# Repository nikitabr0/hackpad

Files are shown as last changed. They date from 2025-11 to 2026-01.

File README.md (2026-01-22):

# nikitabr0's hackpad

[Demo video](https://youtu.be/7ATBC-yoFk0)

<table>
  <tr>
    <td>
    <td>
  </tr>
  <tr>
    <td>
    <td>
  </tr>
</table>   

My hackpad features 9 MX-style keyswitches and two EC11 rotary encoders. It has two modes: media control and gaming mode, the latter being mostly for simulators, that require large amounts of keybinds.

In media control mode the keys can be used for pausing, resuming and switching between audiotracks, as well as for using the calcuator (+, -, *, / and =), while the rotary encoders allow for audio volume and screen brightness control, with their switches set to muting audio and locking the screen.

In gaming mode all switches (including those of EC11s) register as F13-F22 presses, with the rotary encoders triggering Right CTRL + F13/14/15/16 on rotation. These keycodes were choosed as they are not included on most keyboards and thus largely unused.

The firmware if written in KMK for the sake of simplicity, although I may try rewriting it in QMK one day. The CAD was done in FreeCAD.

#

### Schematic


### PCB layout


### Case assembly



#

## Bill of materials:
- 1x Seeed XIAO RP2040 DIP
- 9x MX-style switches
- 2x EC11 rotary encoders
- 9x Blank DSA keycaps
- 11x Through-hole 1N4148 diodes
- 4x M3x5mx4mm heatset inserts

I will be printing the case by myself and as I already have some mounting hardware, I will be using it in this project:
- 4x M3x12 SHCS
- 3x M3x8 SHCS

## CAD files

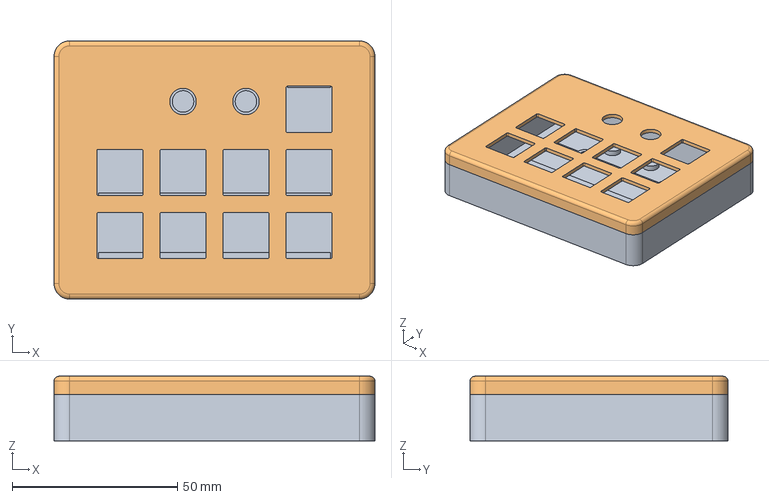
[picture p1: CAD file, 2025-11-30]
CAD/case.step
97.0 x 78.0 x 19.5 mm
Main
Lid

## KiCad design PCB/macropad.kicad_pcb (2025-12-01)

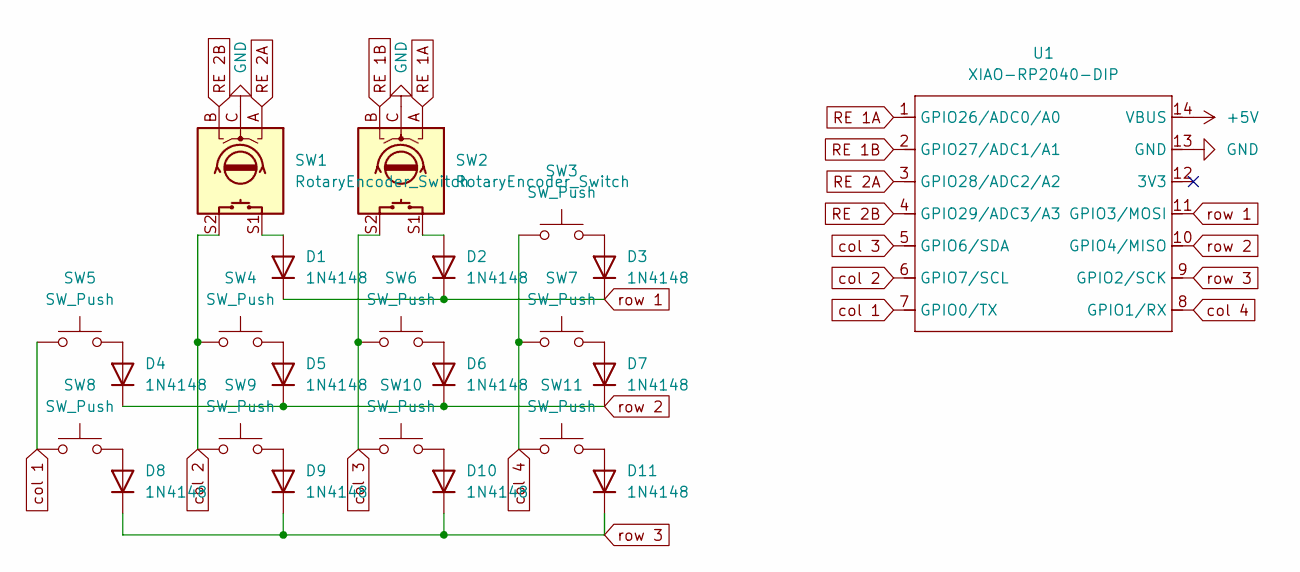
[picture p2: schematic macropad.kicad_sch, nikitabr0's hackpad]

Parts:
D1, D2, D3, D4, D5, D6, D7, D8, D9, D10, D11: 1N4148; D_DO-35_SOD27_P7.62mm_Horizontal
SW1, SW2: RotaryEncoder_Switch; RotaryEncoder_Alps_EC11E-Switch_Vertical_H20mm
SW3, SW4, SW5, SW6, SW7, SW8, SW9, SW10, SW11: SW_Push; SW_Cherry_MX_PCB_1.00u
U1: XIAO-RP2040-DIP

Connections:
+5V: U1.14 (VBUS)
GND: SW1.C, SW2.C, U1.13 (GND)
unnamed: D1.2 (A), SW1.S1
unnamed: D2.2 (A), SW2.S1
unnamed: D3.2 (A), SW3.2
unnamed: D4.2 (A), SW5.2
unnamed: D5.2 (A), SW4.2
unnamed: D6.2 (A), SW6.2
unnamed: D7.2 (A), SW7.2
unnamed: D8.2 (A), SW8.2
unnamed: D9.2 (A), SW9.2
unnamed: D10.2 (A), SW10.2
unnamed: D11.2 (A), SW11.2
RE 1A: SW2.A, U1.1 (GPIO26/ADC0/A0)
RE 1B: SW2.B, U1.2 (GPIO27/ADC1/A1)
RE 2A: SW1.A, U1.3 (GPIO28/ADC2/A2)
RE 2B: SW1.B, U1.4 (GPIO29/ADC3/A3)
col 1: SW5.1, SW8.1, U1.7 (GPIO0/TX)
col 2: SW1.S2, SW4.1, SW9.1, U1.6 (GPIO7/SCL)
col 3: SW2.S2, SW6.1, SW10.1, U1.5 (GPIO6/SDA)
col 4: SW3.1, SW7.1, SW11.1, U1.8 (GPIO1/RX)
row 1: D1.1 (K), D2.1 (K), D3.1 (K), U1.11 (GPIO3/MOSI)
row 2: D4.1 (K), D5.1 (K), D6.1 (K), D7.1 (K), U1.10 (GPIO4/MISO)
row 3: D8.1 (K), D9.1 (K), D10.1 (K), D11.1 (K), U1.9 (GPIO2/SCK)

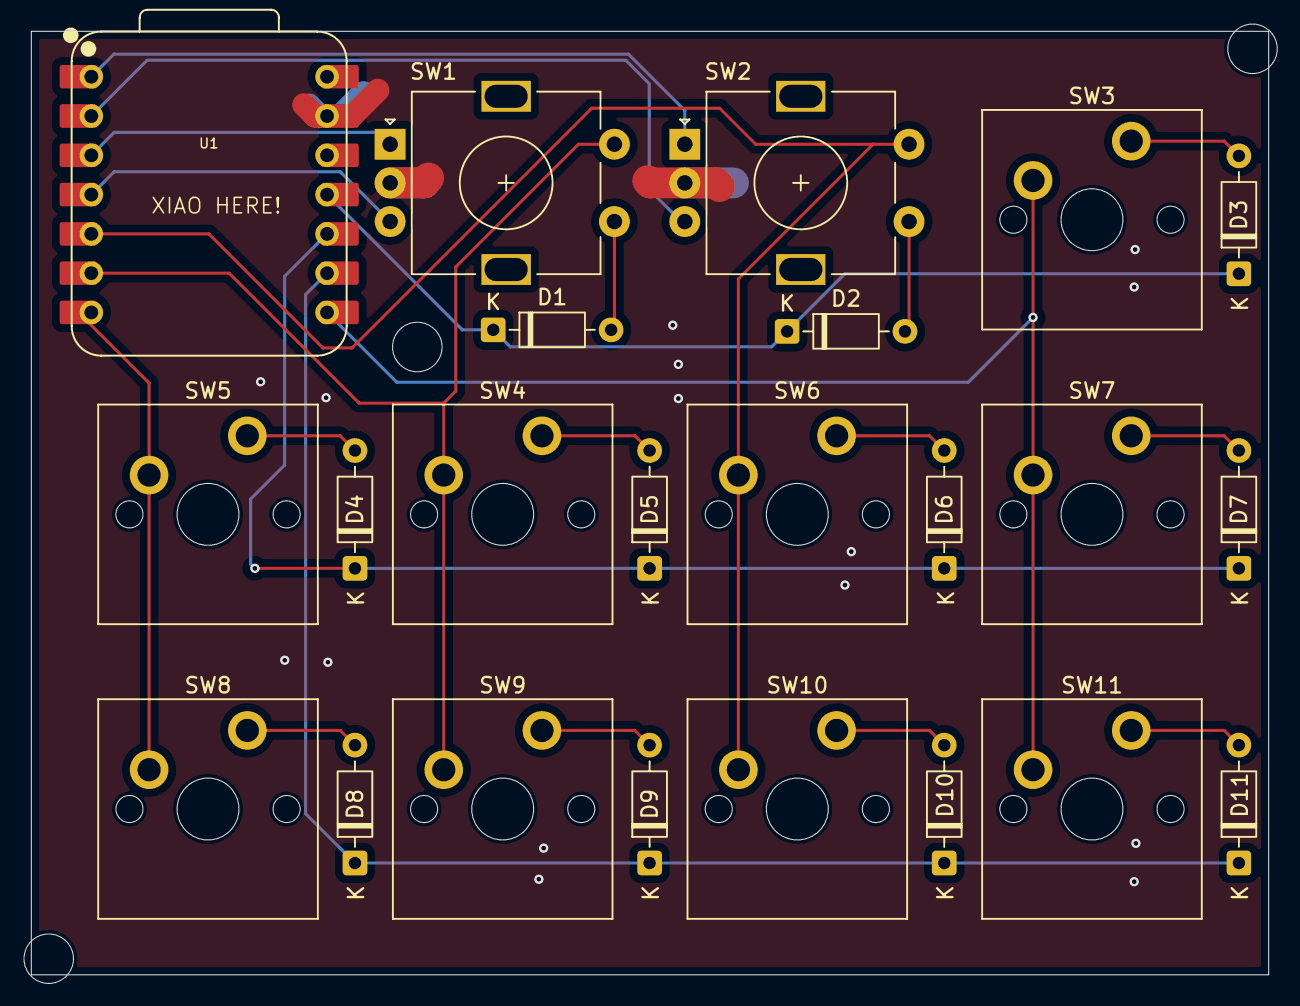
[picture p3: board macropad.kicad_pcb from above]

Board: 2 copper layers, 80.0 x 61.0 mm, 23 parts (0 on the bottom side), 23 nets.

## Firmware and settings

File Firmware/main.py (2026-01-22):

import board

from kmk.kmk_keyboard import KMKKeyboard
from kmk.keys import KC
from kmk.scanners import DiodeOrientation
from kmk.modules.layers import Layers
from kmk.modules.encoder import EncoderHandler
from kmk.extensions.media_keys import MediaKeys


keyboard = KMKKeyboard()
layers = Layers()
encoder_handler = EncoderHandler()
keyboard.modules = [layers, encoder_handler]
keyboard.extensions.append(MediaKeys())


#   Define media control and game mode layers
TO_MEDIA = KC.DF(0)
TO_GAME = KC.DF(1)


encoder_handler.pins = ((board.D0, board.D1, None, True), (board.D2, board.D3, None, True),)

encoder_handler.map = [
    ((KC.AUDIO_VOL_DOWN, KC.AUDIO_VOL_UP), (KC.BRIGHTNESS_DOWN, KC.BRIGHTNESS_UP),), # Control volume and brightness

    ((KC.RCTRL(KC.F13), KC.RCTRL(KC.F14)), (KC.RCTRL(KC.F15), KC.RCTRL(KC.F16)),),    # Right control + F13/F14/F15/F16
]

keyboard.col_pins = (board.D6, board.D5, board.D4, board.D7,)
keyboard.row_pins = (board.D10, board.D9, board.D8)
keyboard.diode_orientation = DiodeOrientation.COL2ROW

keyboard.keymap = [
    [KC.NO, KC.LGUI(KC.L), KC.AUDIO_MUTE, TO_GAME,                                  # Empty cell, mute, lock screen, switch to game mode
     KC.MEDIA_PREV_TRACK, KC.MEDIA_PLAY_PAUSE, KC.MEDIA_NEXT_TRACK, KC.KP_EQUAL,    # Previous track, play/pause, next track, numpad equal
     KC.KP_PLUS, KC.KP_MINUS, KC.KP_ASTERISK, KC.KP_SLASH,],                        # Numpad keys: plus, minus, multiply, divide

    [KC.NO, KC.F13, KC.F14, TO_MEDIA,                                               # Empty cell, F13, F14, switch to media control
     KC.F15, KC.F16, KC.F17, KC.F18,                                                # F15, F16, F17, F18
     KC.F19, KC.F23, KC.F21, KC.F22,],                                              # F19, F20, F21, F22
                                                                                    # All function keys are for mapping in simulators
]


if __name__ == '__main__':
    keyboard.go()

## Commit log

2025-11-30 Added PCB and CAD files
    [case.step, macropad.kicad_pcb, macropad.kicad_sch]
2025-12-01 Added knobs for rotary encoders and KMK firmware
2025-12-01 Fixed ground fill on the PCB
    [macropad.kicad_pcb, macropad.kicad_sch]
